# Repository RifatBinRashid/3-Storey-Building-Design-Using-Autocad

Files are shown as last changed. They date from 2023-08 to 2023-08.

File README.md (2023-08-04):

# 3-Storey-Building-Design-Using-Autocad

A whole plan of 3 storeyed 2 unit building. The building have enough parking space allocated for each flat and also one or two rooms in the basement. 
The AutoCAD drawing fle contains the floor plan, the fitting fixture,conduit plan and connection diagram for each unit and also for the whole building.

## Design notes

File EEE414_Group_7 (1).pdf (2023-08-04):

Project Report | EEE414 | EEE | BUET

## Bangladesh University of Engineering and Technology Department of Electrical &Electronic Engineering

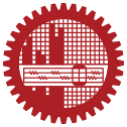
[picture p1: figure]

### Course No. EEE414

### Course Name: Electrical Service Design

## Project: 3-Storey Building Design

## Group-7

Date of Submission: 18/02/2022

Submitted by-

Md. Fazlay Rabbi (1506098)

Tanvir Anjum (1606115)

Rifat Bin Rashid (1606117)

Md. Tanvir Raihan (1606118)

Sabit Mohammad Abdal (1606119)

Ankan Ghosh Dastider (1606120)

Sanwar Ahmed Ovy (1606121)

Md. Rakib Farazi(1606123)

Submitted to-

Talha Ibn Mahmud
Lecturer(PT)
Md. Shoriful Islam
Lecturer(PT)

## Fitting Fixture Layout

# Ground Floor:

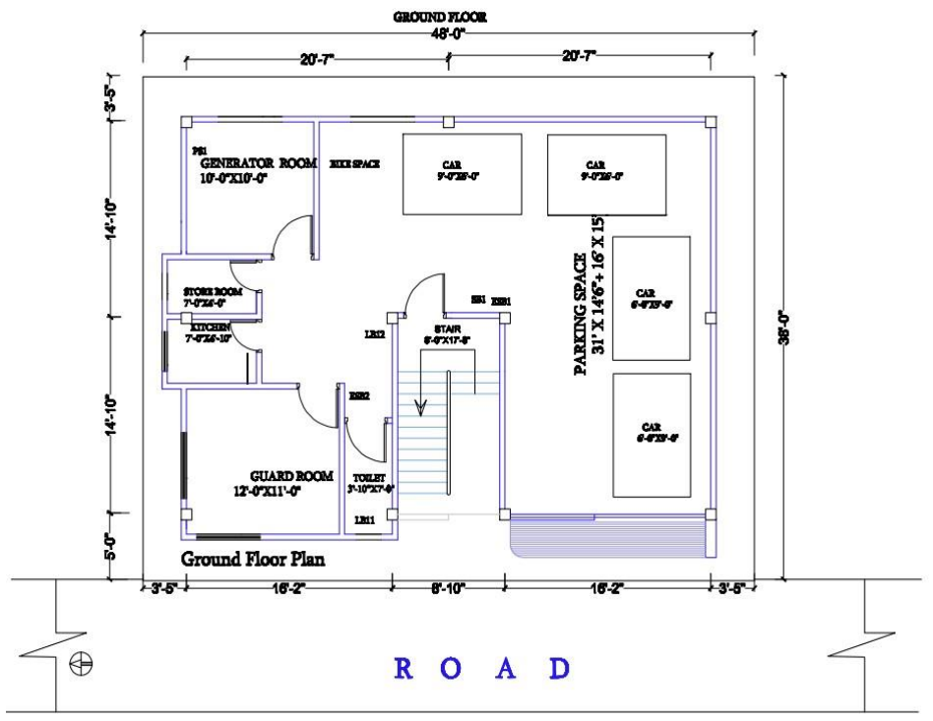
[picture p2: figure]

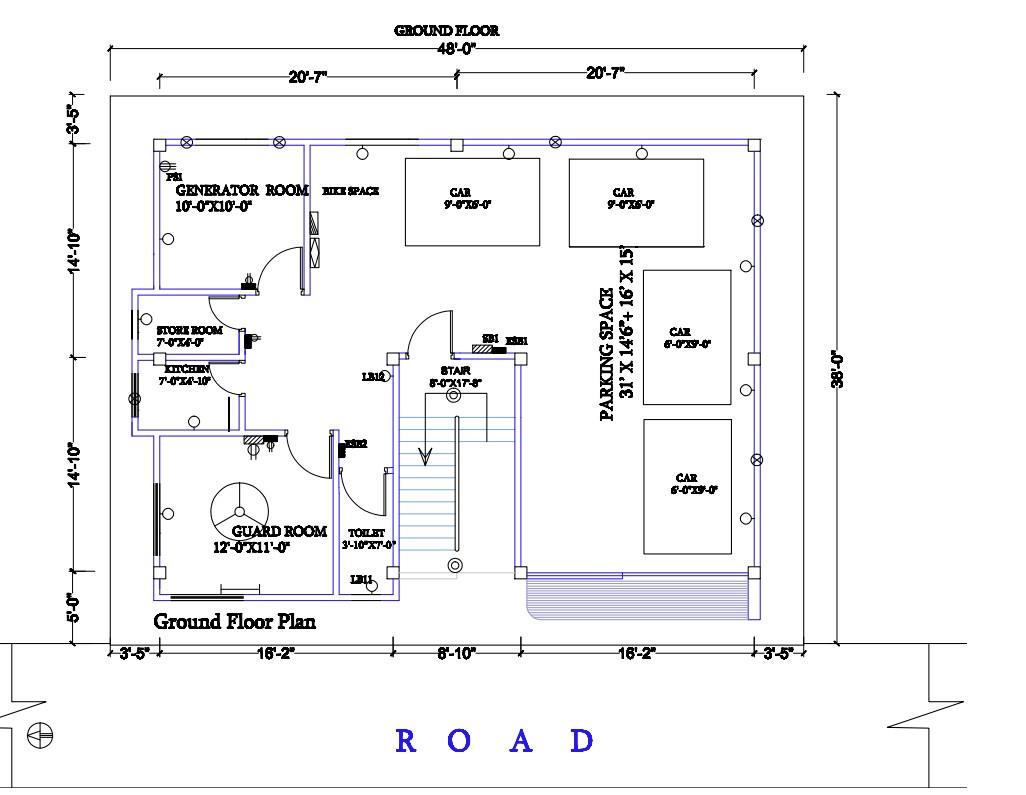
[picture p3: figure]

# First Floor:

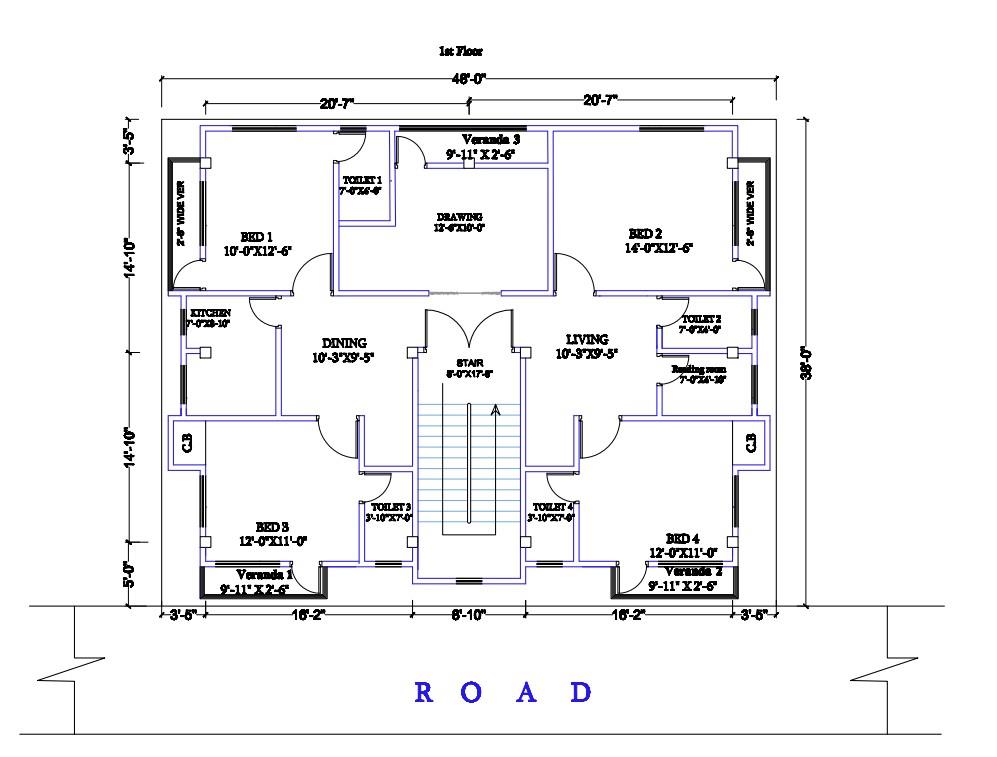
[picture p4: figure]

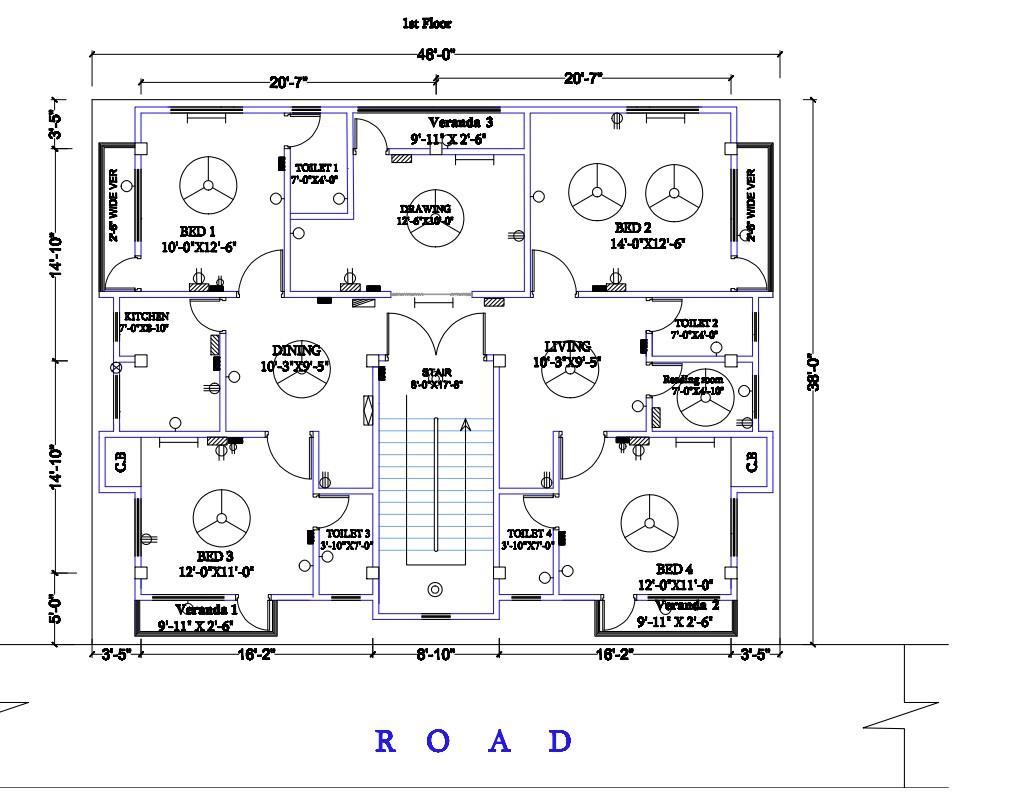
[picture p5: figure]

# Second Floor:

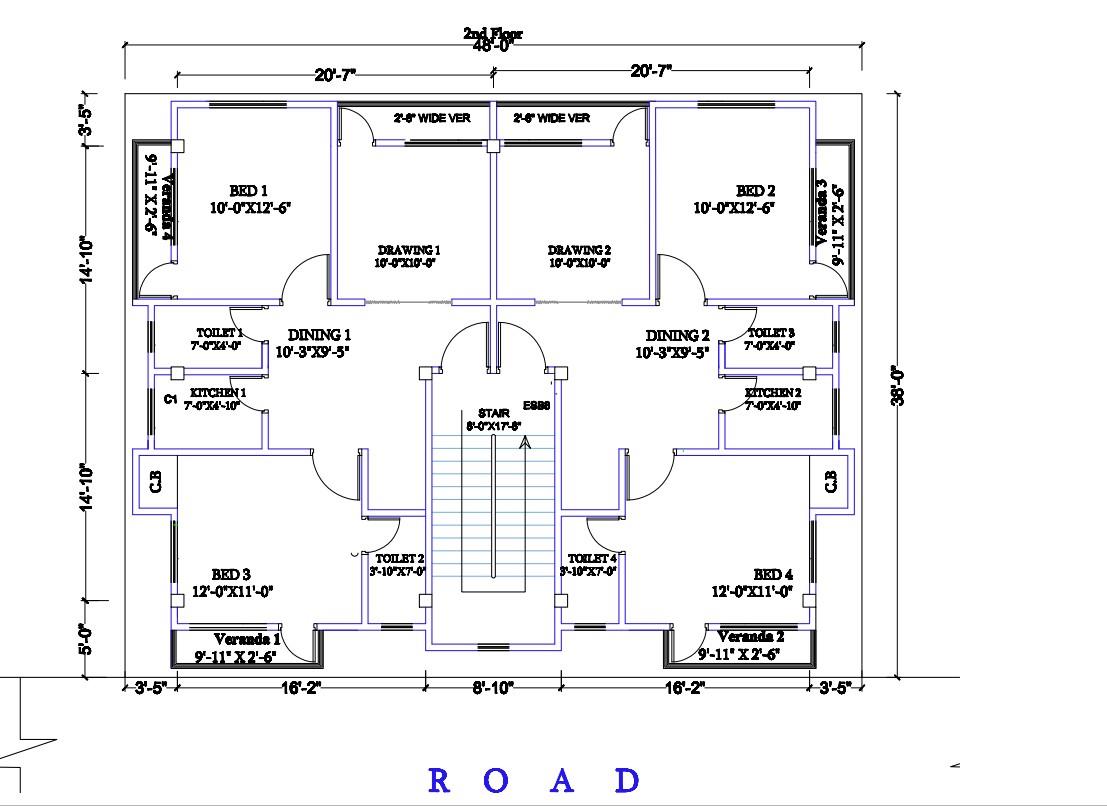
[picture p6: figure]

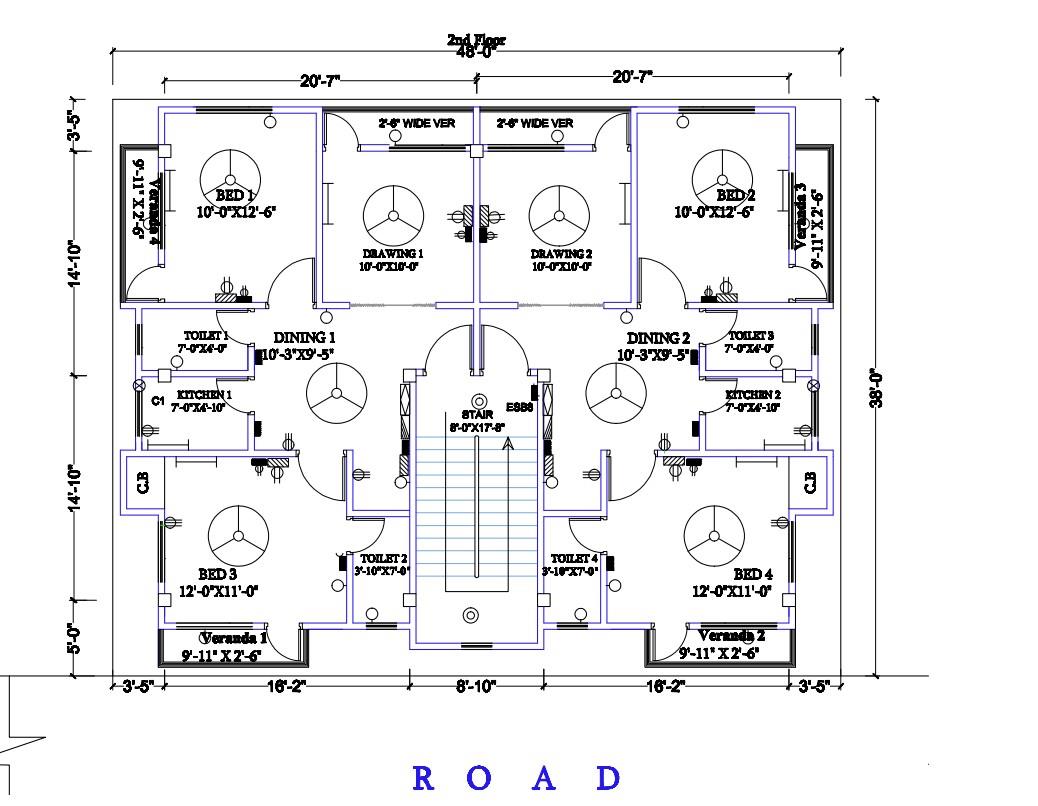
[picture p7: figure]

## Condui Layout:

# Ground Floor:

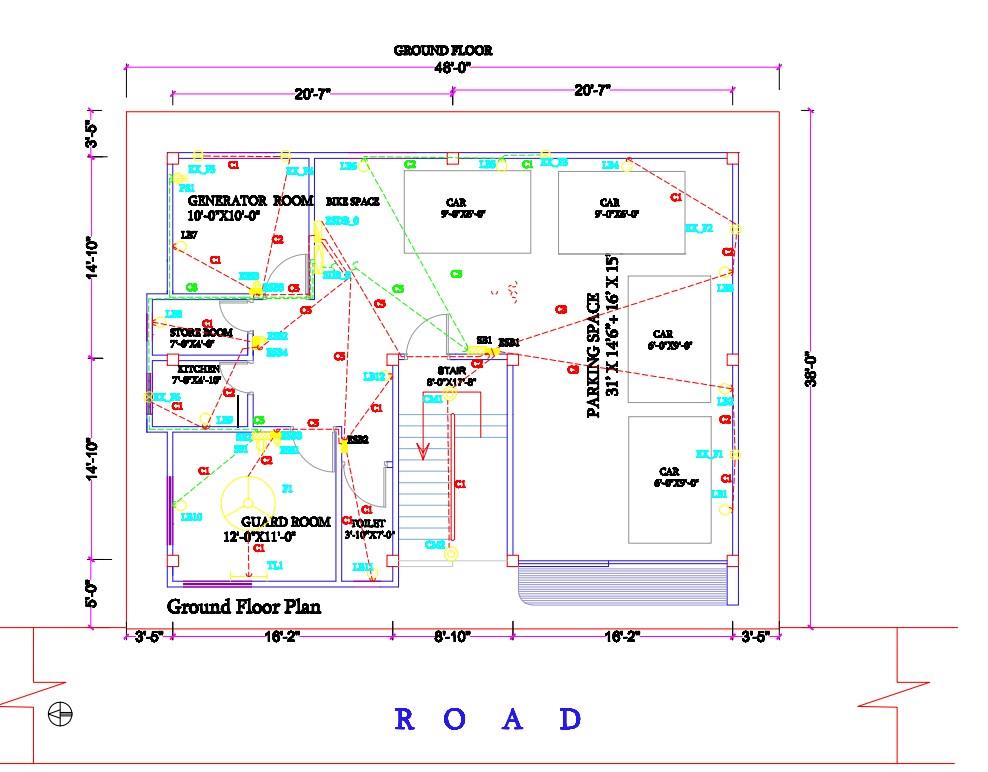
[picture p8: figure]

# First Floor:

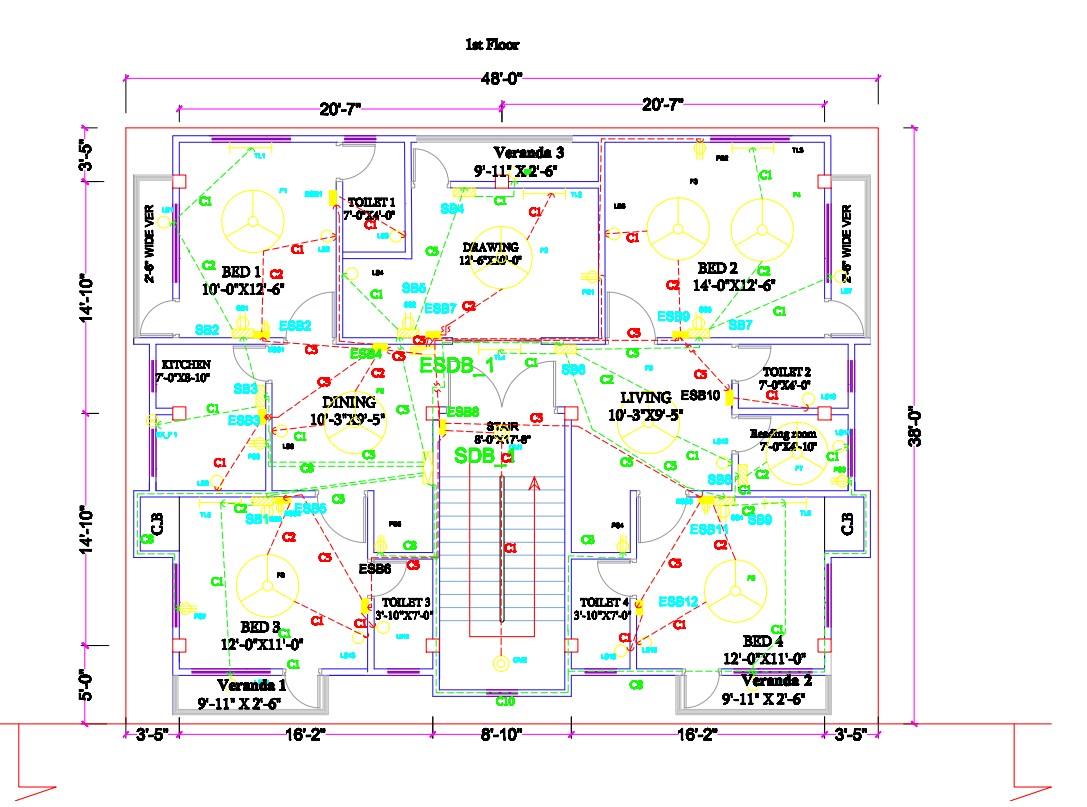
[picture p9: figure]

# Second Floor:

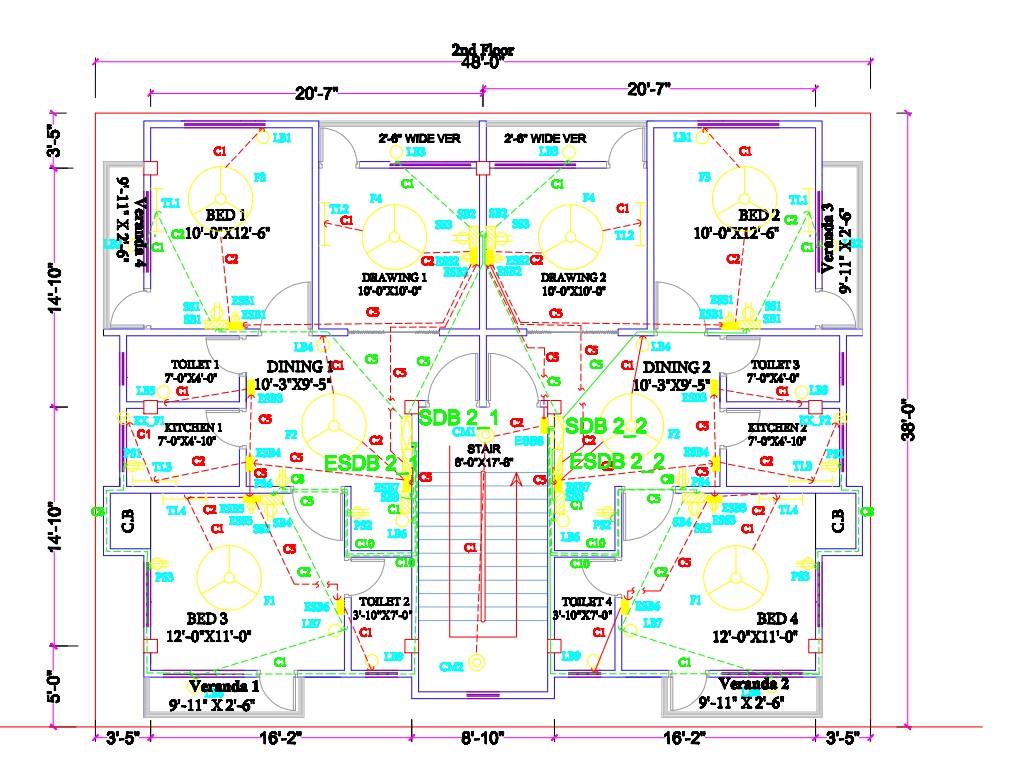
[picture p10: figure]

## SWITCH BOARD DIAGRAM

# GROUND FLOOR

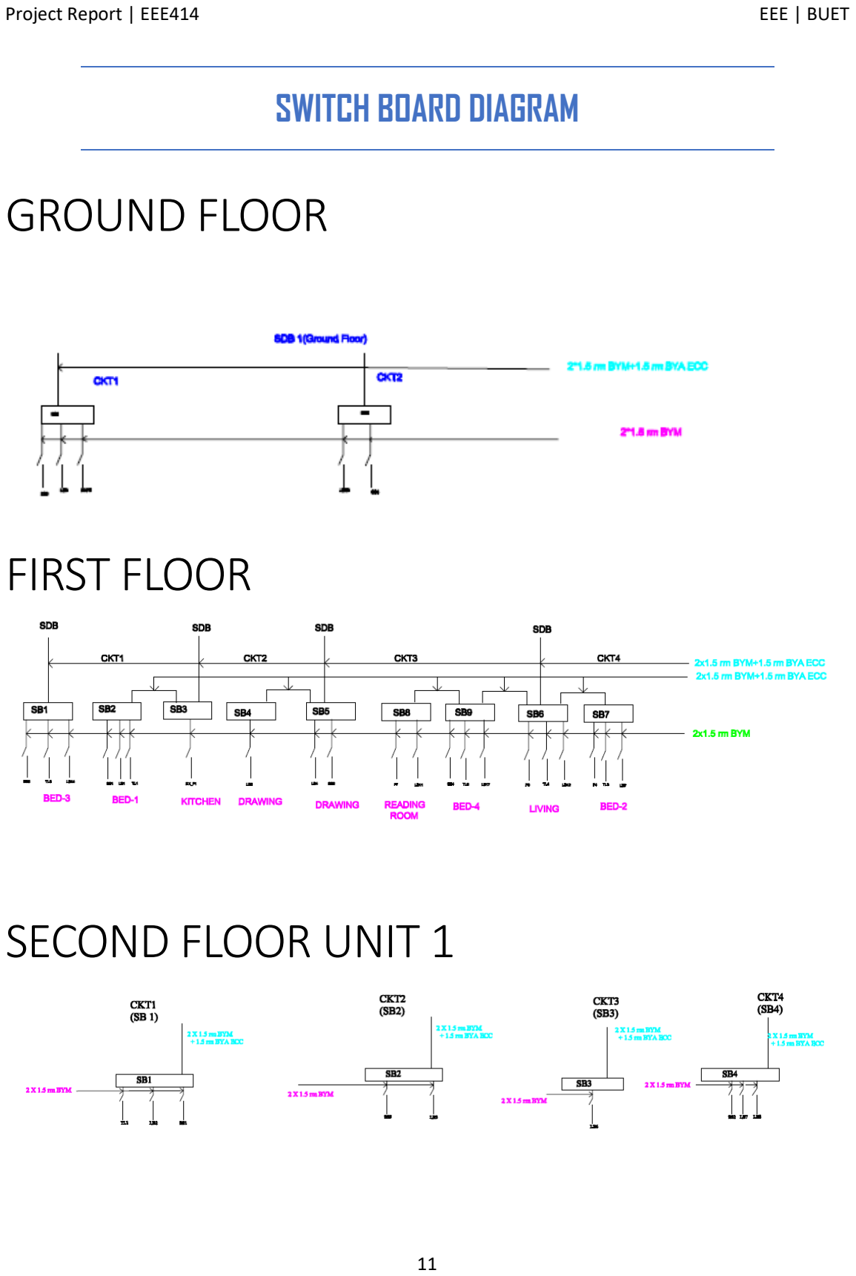
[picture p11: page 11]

# FIRST FLOOR

# SECOND FLOOR UNIT 1

# SECOND FLOOR UNIT 2

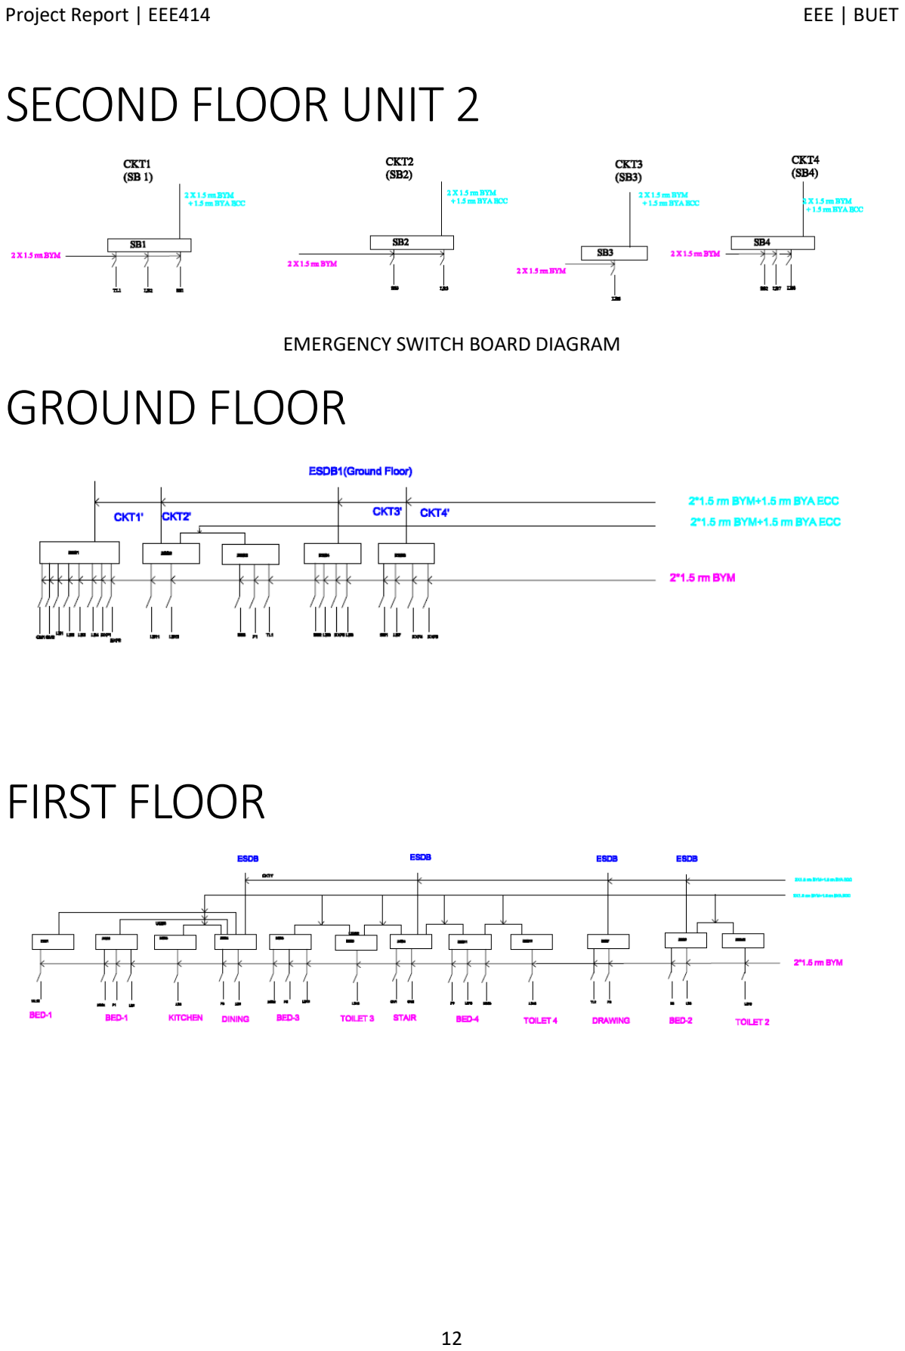
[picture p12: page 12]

EMERGENCY SWITCH BOARD DIAGRAM

# GROUND FLOOR

# FIRST FLOOR

# SECOND FLOOR UNIT 1

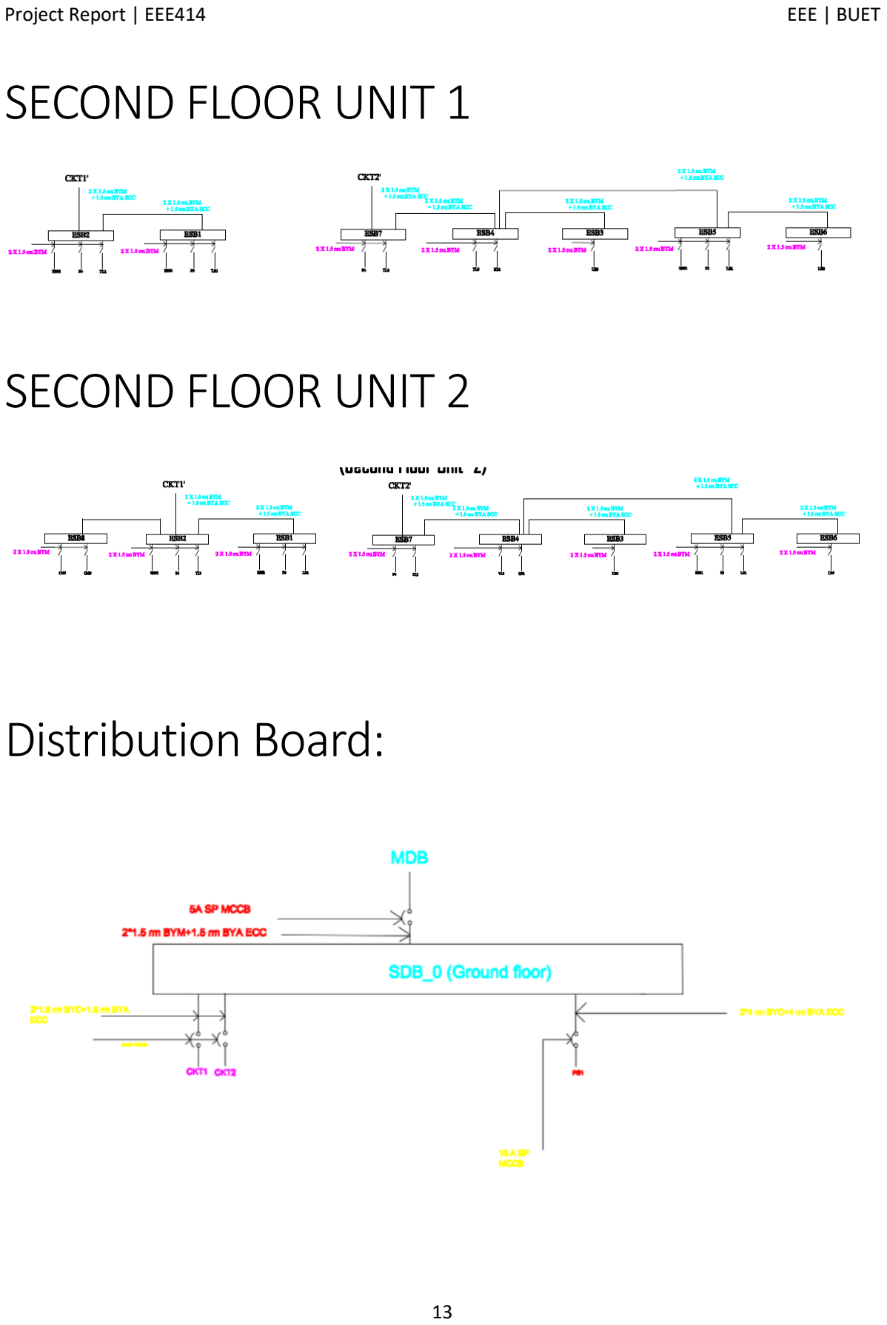
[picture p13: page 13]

# SECOND FLOOR UNIT 2

# Distribution Board:

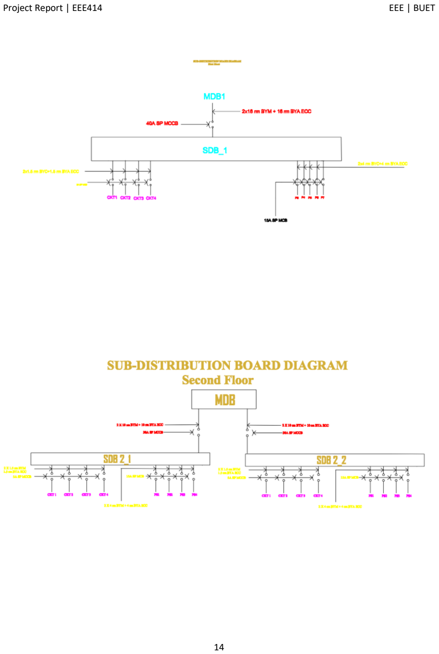
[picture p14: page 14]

# Emergency Distribution Board:

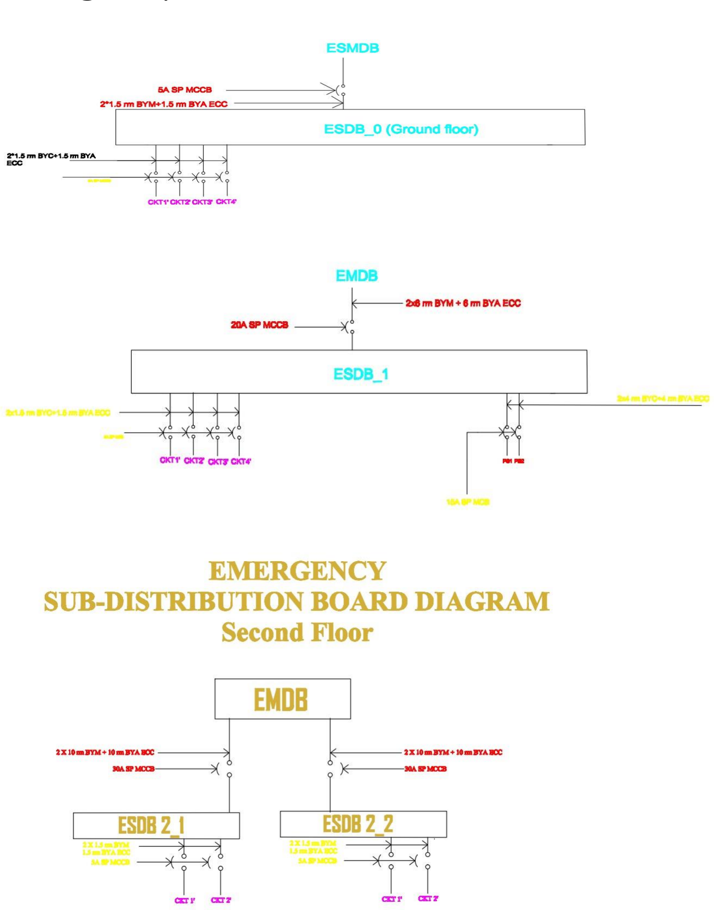
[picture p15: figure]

# Main Distribution Board Layout:

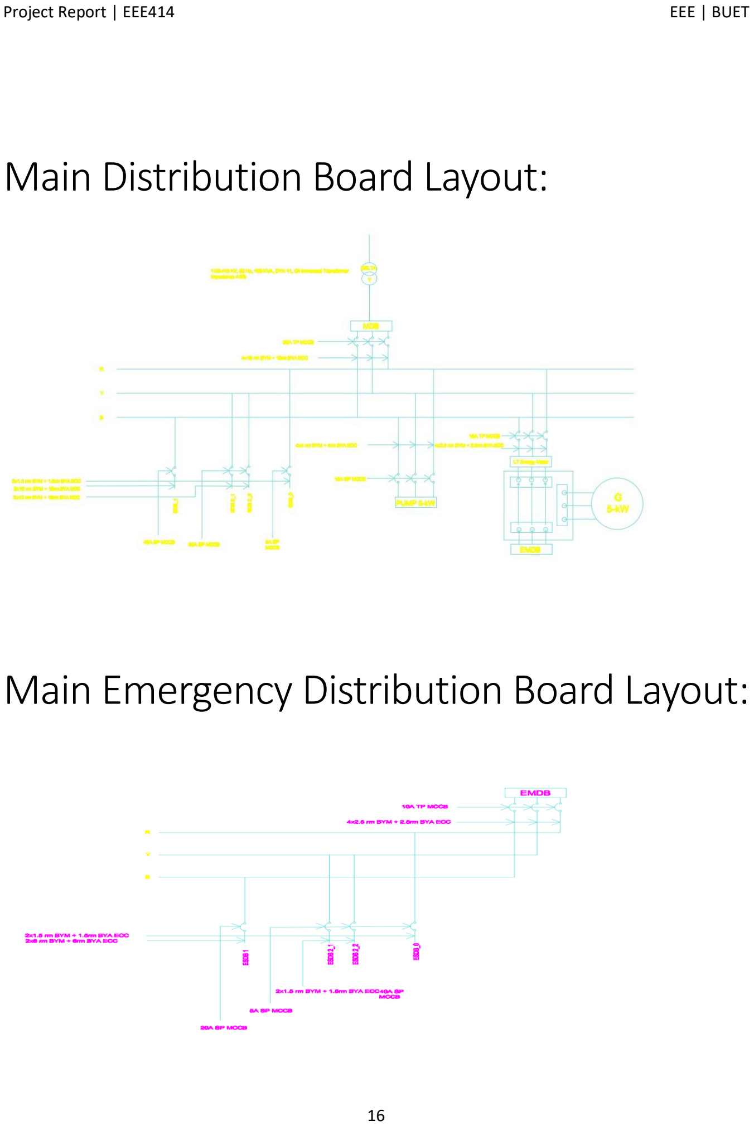
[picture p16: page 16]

# Main Emergency Distribution Board Layout:

## Fitting Fixture Calculation

We know,

E =

n ∗ N ∗ F ∗ UF ∗ LLF
A

, A in m²

E = Illuminance

n = number of lights per illuminance

N = number of lights required

F = lumen of bulb

LLF = Light Loss Factor

UF = Utilization factor

A = area

F =

A
100 , A in sq − ft

Here,

F = number of fans required

## Calculation for Ground Floor:

### Guard Room:

Area= 12’ * 10’=120 sqft = (120x 0.092903) m² =11.14836 m²

Illuminance, E= 100 Lumen/m²

Light Loss Factor and Utilization Factor, LLF x UF = 0.7

Number of lights per illuminaire, n=1

Flux= 1250 Lumen (20W Energy Saving Bulb and Fluorescent Tube Light)

Number of Lights, N= 1.27 ≈ 1

So, 1 Light Bulb is required.

Number of Fans= 1.2 ≈ 1

So, 1 Fan is required.

### Space in front of guard room:

Area= 10’ 6”*5’3” =55.125 sqft = (55.125 x 0.092903)m² =5.1213 m²

Illuminance, E= 100Lumen/m²

Light Loss Factor and Utilization Factor, LLF x UF = 0.7

Number of lights per illuminaire, n=1

Flux= 1250 Lumen (20W Energy Saving Bulb and Fluorescent Tube Light)

Number of Lights, N= 0.5853 ≈ 1

So, 1 Light Bulb is required.

### Common Toilet:

Area= 3’10” x 7’ =26.8sqft = (26.8 x 0.092903) m² =2.5 m²

Illuminance, E= 100 Lumen/m²

Light Loss Factor and Utilization Factor, LLF x UF = 0.7

Number of lights per illuminaire, n=1

Flux= 1250 Lumen (20W Energy Saving Bulb and Fluorescent Tube Light)

Number of Lights, N= 0.285 ≈ 1

So, 1 Light Bulb is required.

### Store Room:

Area= 7’ x 4’ =28sqft = (28 x 0.092903) m² =2.604 m²

Illuminance, E= 100 Lumen/m²

Light Loss Factor and Utilization Factor, LLF x UF = 0.7

Number of lights per illuminaire, n=1

Flux= 1250 Lumen (20W Energy Saving Bulb and Fluorescent Tube Light)

Number of Lights, N= 0.3 ≈ 1

So, 1 Light Bulb is required.

### Kitchen:

Area= 7’x 4’10” =33.83 sqft = (33.83 x 0.092903) m² =3.15 m²

Illuminance, E= 200 Lumen/m²

Light Loss Factor and Utilization Factor, LLF x UF = 0.7

Number of lights per illuminaire, n=1

Flux= 1250 Lumen (20W Energy Saving Bulb and Fluorescent Tube Light)

Number of Lights, N= 0.72 ≈ 1

So, 1 Light bulb is required.

Number of Fans= 0.33 ≈ 1

1 Exhaust Fan is required.

### Generator Room:

Area= 10’ x 10’ =100 sqft = (100 x 0.092903) m² =9.2903 m²

Illuminance, E= 100 Lumen/m²

Light Loss Factor and Utilization Factor, LLF x UF = 0.7

Number of lights per illuminaire, n=1

Flux= 1250 Lumen (20W Energy Saving Bulb and Fluorescent Tube Light)

Number of Lights, N= 1.062 ≈ 1

So, 1 light Bulb is required.

2 Exhaust Fans are provided.

### Garage:

Area= 31’ x 14’6”+ 16’ x 15’ sqft = (689.5x 0.092903) m² = 64.05662 m²

Illuminance, E = 70 Lumen/m²

Light Loss Factor and Utilization Factor, LLF x UF = 0.7

Number of lights per illuminaire, n=1

Flux= 1250 Lumen (20W Energy Saving Bulb and Fluorescent Tube Light)

Number of Lights, N = 5.1245

So, 5 Ceiling-mounted bulbs are required and 3 Exhaust Fans are required.

### Staircases:

Area= 8’ x 17’8” = 141.33 sqft = (141.33 x 0.092903) m² = 13.13 m²

Illuminance, E = 100 Lumen/m²

Light Loss Factor and Utilization Factor, LLF x UF = 0.7

Number of lights per illuminaire, n=1

Flux= 1250 Lumen (20W Energy Saving Bulb)

Number of Lights, N = 1.5 ≈ 2

So, 2 Ceiling-mounted light bulbs are required.

## Calculation for First Floor:

### Bedroom-1:

Area = 10’ x 12’6” = 125 sqft = (126 x 0.092903) m² = 11.613 m²

Illuminance, E= 100 Lumen/m²

Light Loss Factor and Utilization Factor, LLF x UF = 0.7

Number of lights per illuminaire, n=1

Flux= 1250 Lumen (20W Energy Saving Bulb and Fluorescent Tube Light)

Number of Lights, N= 1.33 ≈ 2

So, 1 light bulb and 1 tube light are required.

Number of Fans= 1.26 ≈ 1

So, 1 Fan is required.

### Bedroom-3 and 4:

Area= 12’ x 11” = 132 sqft = (132 x 0.092903) m² = 12.263 m²

Illuminance, E= 100 Lumen/m²

Light Loss Factor and Utilization Factor, LLF x UF = 0.7

Number of lights per illuminaire, n=1

Flux= 1250 Lumen (20W Energy Saving Bulb and Fluorescent Tube Light)

Number of Lights, N= 1.4 ≈ 2

So, 1 light bulb and 1 tube light are required.

Number of Fans= 1.32 ≈ 1

So, 1 Fan is required.

### Bedroom-2:

Area= 14’ x 12’6” = 175 sqft = (175 x 0.092903) m² = 16.26 m²

Illuminance, E= 100 Lumen/m²

Light Loss Factor and Utilization Factor, LLF x UF = 0.7

Number of lights per illuminaire, n=1

Flux= 1250 Lumen (20W Energy Saving Bulb and Fluorescent Tube Light)

Number of Lights, N= 1.86 ≈ 2

So, 1 Light bulb and 1 tube light are required.

Number of Fans= 1.75 ≈ 2

So, 2 Fans are required.

### Drawing room:

Area= 12’6” x 10” = 125 sqft = (126 x 0.092903) m² = 11.613 m²

Illuminance, E= 100 Lumen/m²

Light Loss Factor and Utilization Factor, LLF x UF = 0.7

Number of lights per illuminaire, n=1

Flux= 1250 Lumen (20W Energy Saving Bulb and Fluorescent Tube Light)

Number of Lights, N= 1.33 ≈ 2

So, 1 light bulb and 1 tube light are required.

Number of Fans= 1.26 ≈ 1

So, 1 Fan is required.

### Veranda 1, 2 and 3:

Area= 9’11” x 2’6” = 24.79 sqft = (24.79 x 0.092903) m² = 2.23 m²

Illuminance, E= 70 Lumen/m²

Light Loss Factor and Utilization Factor, LLF x UF = 0.7

Number of lights per illuminaire, n=1

Flux= 1250 Lumen (8W Energy Saving Bulb and Fluorescent Tube Light)

Number of Lights, N= 0.1784 ≈ 1

So, 1 Ceiling-mounted light bulb is required

### Toilet 1 and 3:

Area= 7’ x 4’ =28 sqft = (28 x 0.092903) m² = 2.61 m²

Illuminance, E= 100 Lumen/m²

Light Loss Factor and Utilization Factor, LLF x UF = 0.7

Number of lights per illuminaire, n=1

Flux= 1250 Lumen (20W Energy Saving Bulb and Fluorescent Tube Light)

Number of Lights, N= 0.28 ≈ 1

So, 1 Light Bulb is required.

### Dining room:

Area= 10’3” x 9’5” = 96.52 sqft = (96.52 x 0.092903) m² = 8.96 m²

Illuminance, E= 100 Lumen/m²

Light Loss Factor and Utilization Factor, LLF x UF = 0.7

Number of lights per illuminaire, n=1

Flux= 1250 Lumen (20W Energy Saving Bulb and Fluorescent Tube Light)

Number of Lights, N= 1.024 ≈ 1

So, 1 Light Bulb is required.

Number of Fans= 0.96 ≈ 1

So, 1 Fan is required.

### Living room:

Area= 10’3” x 9’5” = 96.52 sqft = (96.52 x 0.092903) m² = 8.96 m²

Illuminance, E= 100 Lumen/m²

Light Loss Factor and Utilization Factor, LLF x UF = 0.7

Number of lights per illuminaire, n=1

Flux= 1250 Lumen (20W Energy Saving Bulb and Fluorescent Tube Light)

Number of Lights, N= 1.024 ≈ 1

So, 1 Light Bulb is required.

Number of Fans= 0.96 ≈ 1

So, 1 Fan is required.

### Kitchen:

Area= 7’ x 8’10” = 61.83 sqft = (61.83 x 0.092903) m² = 5.745 m²

Illuminance, E= 200 Lumen/m²

Light Loss Factor and Utilization Factor, LLF x UF = 0.7

Number of lights per illuminaire, n=1

Flux= 1250 Lumen (20W Energy Saving Bulb and Fluorescent Tube Light)

Number of Lights, N= 1.313 ≈ 1

So, 1 Light Bulb is required.

Number of Fans= 0.6183 ≈ 1

1 exhaust fan is provided.

### Toilet 2 and 4:

Area= 3’10” x 7’ =26.83 sqft = (26.83 x 0.092903) m² = 2.493 m²

Illuminance, E= 100 Lumen/m²

Light Loss Factor and Utilization Factor, LLF x UF = 0.7

Number of lights per illuminaire, n=1

Flux= 1250 Lumen (20W Energy Saving Bulb and Flouroscent Tube Light)

Number of Lights, N= 0.285 ≈ 1

So, 1 Light Bulb is required.

### Reading room:

Area= 7’ x 4’10” = 33.833 sqft = (33.833 x 0.092903) m² = 3.1432 m²

Illuminance, E= 100 Lumen/m²

Light Loss Factor and Utilization Factor, LLF x UF = 0.7

Number of lights per illuminaire, n=1

Flux= 1250 Lumen (20W Energy Saving Bulb and Fluorescent Tube Light)

Number of Lights, N = 0.359

So, 1 Light Bulb is required.

Number of Fans = 0.33833 ≈ 1

So, 1 Fan is required.

### Corridor and Staircases:

Area= 8’ x 17’8” = 141.33 sqft = (141.33 x 0.092903) m² = 13.13 m²

Illuminance, E= 100 Lumen/m²

Light Loss Factor and Utilization Factor, LLF x UF = 0.7

Number of lights per illuminaire, n=1

Flux= 1250 Lumen (20W Energy Saving Bulb)

Number of Lights, N = 1.5 ≈ 2

So, 2 light bulbs are required.

## Calculation for Second Floor:

### Bedroom-1 and 2:

Area = 10’ x 12’6” = 125 sqft = (126 x 0.092903) m² = 11.613 m²

Illuminance, E= 100 Lumen/m²

Light Loss Factor and Utilization Factor, LLF x UF = 0.7

Number of lights per illuminaire, n=1

Flux= 1250 Lumen (20W Energy Saving Bulb and Fluorescent Tube Light)

Number of Lights, N = 1.33 ≈ 2

So, 1 light bulb and 1 tube light are required.

Number of Fans= 1.26 ≈ 1

So, 1 Fan is required.

### Bedroom-3 and 4:

Area= 12’ x 11” = 132 sqft = (132 x 0.092903) m² = 12.263 m²

Illuminance, E= 100 Lumen/m²

Light Loss Factor and Utilization Factor, LLF x UF = 0.7

Number of lights per illuminaire, n=1

Flux= 1250 Lumen (20W Energy Saving Bulb and Fluorescent Tube Light)

Number of Lights, N= 1.4 ≈ 2

So, 1 light bulb and 1 tube light are required.

Number of Fans= 1.32 ≈ 1

So, 1 Fan is required.

### Drawing room 1 and 2:

Area= 10’ x 10’ = 100 sqft = (100 x 0.092903) m² = 9.29 m²

Illuminance, E= 100 Lumen/m²

Light Loss Factor and Utilization Factor, LLF x UF = 0.7

Number of lights per illuminaire, n=1

Flux= 1250 Lumen (20W Energy Saving Bulb and Fluorescent Tube Light)

Number of Lights, N= 1.06 ≈ 1

So, 1 light bulb is required.

Number of Fans= 1

So, 1 Fan is required.

### Veranda 1, 2 and 3:

Area= 9’11” x 2’6” = 24.79 sqft = (24.79 x 0.092903) m² = 2.23 m²

Illuminance, E= 70 Lumen/m²

Light Loss Factor and Utilization Factor, LLF x UF = 0.7

Number of lights per illuminaire, n=1

Flux= 1250 Lumen (8W Energy Saving Bulb and Fluorescent Tube Light)

Number of Lights, N= 0.1784 ≈ 1

So, 1 Ceiling-mounted light bulb is required

### Toilet 1 and 3:

Area= 7’ x 4’ =28 sqft = (28 x 0.092903) m² =2.61 m²

Illuminance, E= 100 Lumen/m²

Light Loss Factor and Utilization Factor, LLF x UF = 0.7

Number of lights per illuminaire, n=1

Flux= 1250 Lumen (20W Energy Saving Bulb and Fluorescent Tube Light)

Number of Lights, N= 0.298

So, 1 Light Bulb is required.

### Dining room 1 and 2:

Area= 10’3” x 9’5” = 96.52 sqft = (96.52 x 0.092903) m² = 8.96 m²

Illuminance, E= 100 Lumen/m²

Light Loss Factor and Utilization Factor, LLF x UF = 0.7

Number of lights per illuminaire, n=1

Flux= 1250 Lumen (20W Energy Saving Bulb and Fluorescent Tube Light)

Number of Lights, N= 1.024 ≈ 1

So, 1 Light Bulb is required.

Number of Fans= 0.96 ≈ 1

So, 1 Fan is required.

### Kitchen 1 and 2:

Area= 7’ x 8’10” = 61.83 sqft = (61.83 x 0.092903) m² = 5.745 m²

Illuminance, E= 200 Lumen/m²

Light Loss Factor and Utilization Factor, LLF x UF = 0.7

Number of lights per illuminaire, n=1

Flux= 1250 Lumen (20W Energy Saving Bulb and Fluorescent Tube Light)

Number of Lights, N= 1.313 ≈ 1

So, 1 Light Bulb is required.

Number of Fans= 0.6183 ≈ 1

1 exhaust fan is provided.

### Toilet 2 and 4:

Area= 3’10” x 7’ =26.83 sqft = (26.83 x 0.092903) m² = 2.493 m²

Illuminance, E= 100 Lumen/m²

Light Loss Factor and Utilization Factor, LLF x UF = 0.7

Number of lights per illuminaire, n=1

Flux= 1250 Lumen (20W Energy Saving Bulb and Flouroscent Tube Light)

Number of Lights, N= 0.285 ≈ 1

So, 1 Light Bulb is required.

### Corridor and Staircases:

Area= 8’ x 17’8” = 141.33 sqft = (141.33 x 0.092903) m² = 13.13 m²

Illuminance, E= 100 Lumen/m²

Light Loss Factor and Utilization Factor, LLF x UF = 0.7

Number of lights per illuminaire, n=1

Flux= 1250 Lumen (20W Energy Saving Bulb)

Number of Lights, N = 1.5 ≈ 2

So, 2 light bulbs are required.

## Calculation for Conduit:

Legends:

C1= 2 x 1.5rm BYM

C2= 4 x 1.5rm BYM

C3= 6 x 1.5rm BYM

C4= 8 x 1.5rm BYM

C5= 2 x 1.5rm BYM + 1.5 rm BYA ECC

C6= 2 x 2.5rm BYM + 2.5 rm BYA ECC

C7= 4 x 2.5rm BYM + 2.5 rm BYA ECC

C8= 2 x 4rm BYM + 4 rm BYA ECC

C10= 4 x 4rm BYM + 2 x 4 rm BYA ECC

C12= 2 x 10rm BYM + 10 rm BYA ECC

C13= 2 x 16rm BYM + 16 rm BYA ECC

5A → 1.5rm (6 Cable for ¾” , 10 Cable for 1”)

10A → 2.5rm (4 Cable for ¾” , 7 Cable for 1”)

15A → 4rm(3 Cable for ¾” , 5 Cable for 1”)

20A → 6rm (2 Cable for ¾” , 4 Cable for 1”)

Formula for ampere rating, I = PV ∗ pf (A)PV ∗ pf (A)

pf= 0.7

Energy saving bulb = 20W

Tubelight =20W

Ceiling Light = 20W

Ceiling Fan = 100W

Switchboard Socket= 100W

Exhaust Fan = 60W

All internal wires are below 5A rating, so 2 x 1.5 rm BYM is used in all internal wiring.

## Ground Floor:

To Sub Distribution Board (SDB1) of Ground Floor Unit:

CKT1 Rating (SB1)

I =

20(LB6)+20(LB55)+60(EX_F3) 220∗0.7

(A)

=0.6493 A

So, 2 x 1.5 rm BYM + 1.5 BYA ECC are used.

CKT2 Rating (SB2)

I =

20(LB10)+100(SS4)
220∗0.7

(A)

=0.779 A

So, 2 x 1.5 rm BYM + 1.5 BYA ECC are used.

To Emergency Sub Distribution Board (ESDB1) of Ground Floor Unit:

CKT1’ Rating (ESB1)

I =

20(LB1)+20(LB2)+20(LB3)+20(LB4)+60(EX_F1)+60(EX_F2)+20(CM1)+20(CM2) 220∗0.7

(A)

=1.5584 A

So, 2 x 1.5 rm BYM + 1.5 BYA ECC are used.

CKT2’ Rating (ESB2 and ESB3)

I =

20(LB11)+20(LB12)+100(SS3)+100(F1)+20(TL1) 220∗0.7

(A)

=1.6883 A

So, 2 x 1.5 rm BYM + 1.5 BYA ECC are used.

CKT3’ Rating (ESB4)

I =

100(SS2)+20(LB9)+60(EX_F6)+20(LB8) 220∗0.7

(A)

=1.2987 A

So, 2 x 1.5 rm BYM + 1.5 BYA ECC are used.

CKT4’ Rating (ESB5)

I =

100(SS1)+20(LB7)+60(EX_F4)+60(EX_F5) 220∗0.7

(A)

=1.5584 A

So, 2 x 1.5 rm BYM + 1.5 BYA ECC are used.

## Calculations for SDB_0 (Ground Floor):

SDB1 LOAD = TOTAL LOAD*0.7+ TOTAL P SOCKET LOAD*0.3

TOTAL LOAD=CKT1 LOAD + CKT2 LOAD +CKT3 LOAD+ CKT4 LOAD

P SOCKET LOAD = 3000W

CKT1 LOAD=100W

CKT2 LOAD=120W

TOTAL LOAD=220W

SDB LOAD = 220*0.7+ 1*3000*0.2 =754W

SDB CURRENT =

SDB LOAD
V∗pf

(A)=

754
220∗0.7

(A)=4.836 A

So, 2 x 1.5 rm BYM + 1.5 rm BYA ECC are used.

## Calculations for ESDB_0 (Ground Floor):

ESDB LOAD = TOTAL LOAD*0.7+ TOTAL P SOCKET LOAD*0.3

TOTAL LOAD=CKT1’ LOAD + CKT2’ LOAD +CKT3’ LOAD+ CKT4’ LOAD

P SOCKET LOAD = 3000W

CKT1’ LOAD=240W

CKT2’ LOAD=260W

CKT3’ LOAD=200W

CKT4’ LOAD=240W

TOTAL LOAD=940W

ESDB1 LOAD = 940*0.7=658W

ESDB1 CURRENT =

SDB LOAD
V∗pf

(A)=

658
220∗0.7

(A)=4.273 A

So, 2 x 1.5 rm BYM + 1.5 rm BYA ECC are used.

## First Floor:

To Sub Distribution Board (SDB1) of First Floor Unit:

CKT1 Rating (SB1)

I =

20(LB14)+20(TL5)+100(SS5)
220∗0.7

(A)

=0.909 A

So, 2 x 1.5 rm BYM + 1.5 BYA ECC are used.

CKT2 Rating (SB2,SB3)

I =

20(TL1)+20(LB1)+100(SS1)+60(EX_F1) 220∗0.7

(A)

=1.30 A

So, 2 x 1.5 rm BYM + 1.5 BYA ECC are used.

CKT3 Rating (SB4, SB5)

I =

20(LB4)+20(LB5)+100(SS2)
220∗0.7

(A)

=0.909 A

So, 2 x 1.5 rm BYM + 1.5 BYA ECC are used.

CKT4 Rating (SB6,SB7,SB8,SB9)
I=

100(F7)+20(LB11)+100(SS4)+20(TL6)+20(LB17)+100(F6)+20(TL4)+20(LB12)+100(F4)+20(TL3)+20(LB7) 220∗0.7
(A) =3.50 A

So, 2 x 1.5 rm BYM + 1.5 BYA ECC are used.

## To Emergency Sub Distribution Board (ESDB1) of First Floor :

CKT1’ Rating (ESB1,ESB2,ESB3,ESB4)

I =

20(LB3)+20(LB2)+100(ESS1)+100(F1)+20(LB8)+100(F5)+20(LB9) 220∗0.7

(A)

=2.46 A

So, 2 x 1.5 rm BYM + 1.5 BYA ECC are used.

CKT2’ Rating (ESB5,SB6,ESB8,ESB11,ESB2)
I=

100(F8)+(LB13)20+(ESS2)100+20(LB15)+20(CM1)+20(CM2)+100(F9)+20(LB16)+100(ESS3)+20(LB15) 220∗0.7
(A) =3.37 A

So, 2 x 1.5 rm BYM + 1.5 BYA ECC are used.

CKT3’ Rating (ESB7 )

I =

20(TL2)+100(F2)
220∗0.7
(A) =0.77 A

So, 2 x 1.5 rm BYM + 1.5 BYA ECC are used.

CKT4’ Rating (ESB9,ESB10 )

I =

20(LB6)+100(F3)+20(LB10)
220∗0.7
(A) =0.909 A

So, 2 x 1.5 rm BYM + 1.5 BYA ECC are used.

## Calculations for SDB_1 (1st Floor):

SDB LOAD = TOTAL LOAD*0.7+ TOTAL P SOCKET LOAD*0.3

TOTAL LOAD=CKT1 LOAD + CKT2 LOAD +CKT3 LOAD+ CKT4 LOAD

P SOCKET LOAD = 3000W

CKT1 LOAD=140W

CKT2 LOAD=200W

CKT3 LOAD=140W

CKT4 LOAD=540W

TOTAL LOAD=1020W

SDB LOAD = 1020*0.7+ 5*3000*0.3 =5214 W

SDB CURRENT =

SDB LOAD
V∗pf

(A)=

5214
220∗0.7

(A)=33.86 A

So, 2 x 16 rm BYM + 16 rm BYA ECC are used.

## Calculations for ESDB_1 (1st Floor):

SDB LOAD = TOTAL LOAD*0.7+ TOTAL P SOCKET LOAD*0.3

TOTAL LOAD=CKT1’ LOAD + CKT2’ LOAD +CKT3’ LOAD+ CKT4’ LOAD

P SOCKET LOAD = 3000W

CKT1’ LOAD=380W

CKT2’ LOAD=520W

CKT3’ LOAD=120W

CKT4’ LOAD=140W

TOTAL LOAD=1160W

ESDB LOAD = 1160*0.7+3000*2*0.3=2612W

ESDB CURRENT =

SDB LOAD
V∗pf

(A)=

2612
220∗0.7

(A)=16.96 A

So, 2 x 6 rm BYM + 6 rm BYA ECC are used.

## Second Floor:

## To Sub Distribution Board (SDB1) of Second Floor Unit:

CKT1 Rating (SB1)

I =

20(LB2)+20(TL1)+100(SS1)
220∗0.7
(A) =0.909 A

So, 2 x 1.5 rm BYM + 1.5 BYA ECC are used.

CKT2 Rating (SB2)

I =

(LB3)20+(SS3)100
220∗0.7
(A) =0.779 A

So, 2 x 1.5 rm BYM + 1.5 BYA ECC are used.

CKT3 Rating (SB3)

I =

20(LB4)
220∗0.7
(A) =0.13A

So, 2 x 1.5 rm BYM + 1.5 BYA ECC are used.

CKT4 Rating (SB4)

I =

20(LB7)+20(LB8)+100(SS2)
220∗0.7
(A) =0.909 A

So, 2 x 1.5 rm BYM + 1.5 BYA ECC are used.

## To Sub Distribution Board (SDB2) of Second Floor unit:

CKT1 Rating (SB1)

I =

20(LB2)+20(TL1)+100(SS1)
220∗0.7
(A) =0.909 A

So, 2 x 1.5 rm BYM + 1.5 BYA ECC are used.

CKT2 Rating (SB2)

I =

(LB3)20+(SS3)100
220∗0.7
(A) =0.779 A

So, 2 x 1.5 rm BYM + 1.5 BYA ECC are used.

CKT3 Rating (SB3)

I =

20(LB4)
220∗0.7
(A) =0.13A

So, 2 x 1.5 rm BYM + 1.5 BYA ECC are used.

CKT4 Rating (SB4)

I =

20(LB7)+20(LB8)+100(SS2)
220∗0.7
(A) =0.909 A

So, 2 x 1.5 rm BYM + 1.5 BYA ECC are used.

## To Emergency Sub Distribution Board (ESDB1) of 2

## nd floor:

CKT1’ Rating (ESB1,ESB2)

I =

100(F3)+20(LB1)+100(ESS1)+100(F4)+20(TL2)+100(ESS2) 220∗0.7

(A) =2.8571A

So, 2 x 1.5 rm BYM + 1.5 BYA ECC are used.

CKT2’ Rating (ESB3,ESB4,ESB5,ESB6,ESB7)

I=

20(LB5)+20(TL3)+60(EX1)+100(ESS1)+20(TL2)+100(F4)+20(LB9)+100(F3)+20(LB1) 220∗0.7

(A) =2.987A

So, 2 x 1.5 rm BYM + 1.5 BYA ECC are used.

## To Emergency Sub Distribution Board (ESDB2) of Second Floor:

CKT1’ Rating (ESB1,ESB2,ESB8)

I =

100(F3)+20(LB1)+100(ESS1)+100(F4)+20(TL2)+100(ESS2)+20(CM1)+20(CM2) 220∗0.7

(A) =3.1168A

So, 2 x 1.5 rm BYM + 1.5 BYA ECC are used.

CKT2’ Rating (ESB3,ESB4,ESB5,ESB6,ESB7)
I=

20(LB5)+20(TL3)+60(EX1)+100(ESS1)+20(TL2)+100(F4)+20(LB9)+100(F3)+20(LB1) 220∗0.7

(A) =2.987A

So, 2 x 1.5 rm BYM + 1.5 BYA ECC are used.

## Calculations for SDB 2_1 (Second Floor):

SDB LOAD = TOTAL LOAD*0.7+ TOTAL P SOCKET LOAD*0.3

TOTAL LOAD=CKT1 LOAD + CKT2 LOAD +CKT3 LOAD+ CKT4 LOAD

P SOCKET LOAD = 3000W

CKT1 LOAD=140W

CKT2 LOAD=120W

CKT3 LOAD= 20W

CKT4 LOAD=140W

TOTAL LOAD=420W

SDB LOAD = 420*0.7+ 4*3000*0.3 =3894W

SDB CURRENT =

SDB LOAD
V∗pf

(A)=

3894
220∗0.7

(A)=25.286 A

So, 2 x 10 rm BYM + 10 rm BYA ECC are used.

## Calculations for SDB 2 (2

## nd floor):

SDB LOAD = TOTAL LOAD*0.7+ TOTAL P SOCKET LOAD*0.3

TOTAL LOAD=CKT1 LOAD + CKT2 LOAD +CKT3 LOAD+ CKT4 LOAD

P SOCKET LOAD = 3000W

CKT1 LOAD=140W

CKT2 LOAD=120W

CKT3 LOAD= 20W

CKT4 LOAD=140W

TOTAL LOAD=420W

SDB LOAD = 420*0.7+ 4*3000*0.3 =3894W

SDB CURRENT =

SDB LOAD
V∗pf

(A)=

3894
220∗0.7

(A)=25.286 A

So, 2 x 10 rm BYM + 10rm BYA ECC are used.

## Calculations for ESDB 2_1 (Second Floor):

ESDB LOAD = TOTAL LOAD*0.7+ TOTAL P SOCKET LOAD*0.3

TOTAL LOAD=CKT1’ LOAD + CKT2’ LOAD

P SOCKET LOAD = 3000W

CKT1’ LOAD=440W

CKT2’ LOAD=460W

TOTAL LOAD=900W

ESDB LOAD = 900*0.7=630W

ESDB CURRENT =

SDB LOAD
V∗pf

(A)=

630
220∗0.7

(A)=4.0909 A

So, 2 x 1.5 rm BYM + 1.5 rm BYA ECC are used.

## Calculations for ESDB 2_1 (Second Floor):

ESDB LOAD = TOTAL LOAD*0.7+ TOTAL P SOCKET LOAD*0.3

TOTAL LOAD=CKT1’ LOAD + CKT2’ LOAD

P SOCKET LOAD = 3000W

CKT1’ LOAD=480W

CKT2’ LOAD=460W

TOTAL LOAD=940W

ESDB LOAD = 940*0.7=658W

ESDB CURRENT =

SDB LOAD
V∗pf

(A)=

658
220∗0.7

(A)=4.2727 A

So, 2 x 1.5 rm BYM + 1.5 rm BYA ECC are used.

## Calculations for EMDB:

EMDB Load = Total ESDB Load x 0.7

Total ESDB Load = ESDB_Gnd_unit + SDB_1ST Floor + ESDB_2nd Floor_U1 + ESDB_2nd Floor_U1

= 658 + 2612 + 630 + 658

= 4558 W

EMDB Current = EMDB Load √3∗Line Voltage∗pf

Phase Voltage = 220 V

Line Voltage = √3 * 220 V = 381.05 V

Power Factor, pf = 0.7

EMDB Load = 4558 x 0.7 = 3190.6 W

EMDB current =

| 3190.6 √3 ×381.05×0.7
= 6.9 A

So, 10 A TP MCCB is needed from EMDB to MDB

A 5 KW Generator is used to supply the EMDB Load through an ATS.

Calculations for MDB

MDB load = Total SDB load x 0.7 + (EMDB load + Pump load) x 0.7

Total SDB load = SDB_Gnd_unit + SDB_1st Floor + SDB_2nd Floor_U1 + SDB_2nd Floor_U2

= 754+ 5214 + 3894 + 3894

= 13.756 KW

MDB current =

MDB Load
√3 ∗ Line Voltage ∗ pf

Phase Voltage = 220 V

Line Voltage = √3 x 220 V = 381.05 V

Power Factor, pf = 0.95 (Due to PFI plant)

Total SDB load = 13756 W

EMDB load = 3192 W

Pump load = 5000 W

MDB load = 13756 x 0.7 + (3192 + 5000) x 0.7 = 15362.6 W

MDB current =

15362.6
√3 ×381.05×0.95

= 24.50 A

So, 30 A TP MCCB is needed from MDB to Main Line

❖ Calculations for PFI Plant:

cosθ = 0.7, sinθ = √1 − (cosθ)
| 2 = 0.714

Q = 3VIsinθ = Ptanθ = 15.67 KVAR

After pf improvement sinθ = 1

I =

Q
3 × V × sinθ = 23.74 A

So, 30A TP MCCB is needed from PFI to MDB

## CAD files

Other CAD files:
EEE414_Group7.dwg
